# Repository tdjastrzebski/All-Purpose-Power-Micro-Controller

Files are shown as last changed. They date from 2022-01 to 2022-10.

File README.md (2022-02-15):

# All-purpose Power Micro Controller

This general purpose power micro controller features:
* Wheatstone Bridge front-end
* New Texas Instruments [INA823](https://www.ti.com/product/INA823) instrumentation amplifier (see schematic for alternatives)
* Accurate Texas Instruments [REF2030](https://www.ti.com/product/REF2030) 1.5/3V dual reference voltage source (<0.05%, 1.5 ppm/°C typ.)
* 48-pin [STM32G0B1CE](https://www.st.com/en/microcontrollers-microprocessors/stm32g0b1ce.html) 512kB flash, 144 kB RAM MPU (64kB flash minimum - see schematic for alternatives)
* Popular [Waveshare 18179](https://www.waveshare.com/1.3inch-oled-module-c.htm) 128x64 1.3" OLED display
* [STLINK-V3](https://www.st.com/en/development-tools/stlink-v3mini.html) mini and STLINK-V2 debug connectors, Segger J-Link mini supported.
* Rotary encoder and EEPROM  
* Small dimensions - only 85x50mm

Optional components:
* USB socket, can be used as a power source
* Real Time Clock (RTC) with quartz crystal oscillator
* Miniature battery or supercapacitor for RTC and memory backup
* Opto-isolated serial port (RX/TX)
* I2C port
* Two buffered DACs
* Larger [Waveshare 14747](https://www.waveshare.com/1.5inch-rgb-oled-module.htm) 128x128 1.5" RGB OLED display
* Two potentiometers for fine-tuning (gain and zero)

The device has been designed to be easily configured - e.g. here as a **Weller WSP80** station/controller powered from a standard 30V/5A bench power supply. I have built this universal controller to test some design concepts and have used it intensively for over a year as a **Weller WSP80** soldering iron controller.  
Published schematic includes probably the final 3rd version, slightly improved over what is presented on the pictures (2nd version). Controller can be easily configured to work with any NPT/PPT thermistor or a thermo-couple.

Language: C/C++

Environment: Cube IDE, Cube MX or VS Code - see [VS Code Environment Setup](Software/EnvironmentSetup.md)

License:
* [Software](Software) is released under MIT license.
* [Hardware](Hardware) KiCad design is released under Attribution-NonCommercial-NoDerivatives 4.0 International (CC BY-NC-ND 4.0) License.

Reviews:
* [ANOTHER NEAT GENERAL PURPOSE SOLDERING IRON DRIVER](https://hackaday.com/2022/01/31/another-neat-general-purpose-soldering-iron-driver) by Dave Rowntree

Improvement ideas (help wanted):
* Detecting idle state by analyzing temperature fluctuations and implementing auto sleep mode.
* Implementing self-calibration (PWM duty cycle) algorithm to increase temp precision by analyzing rate of temperature growth.
* Eliminate PWM - it adds significant ripple to the measured signal.

This repo contains complete documentation. If you are interested in building this device and need more details, please let me know rising an issue on GitHub.  
Improvements, suggestions and PRs are more than welcome - rise GitHub issue.  
Finally, if you like this project do not hesitate to give it a star to let others know it is worth checking out.

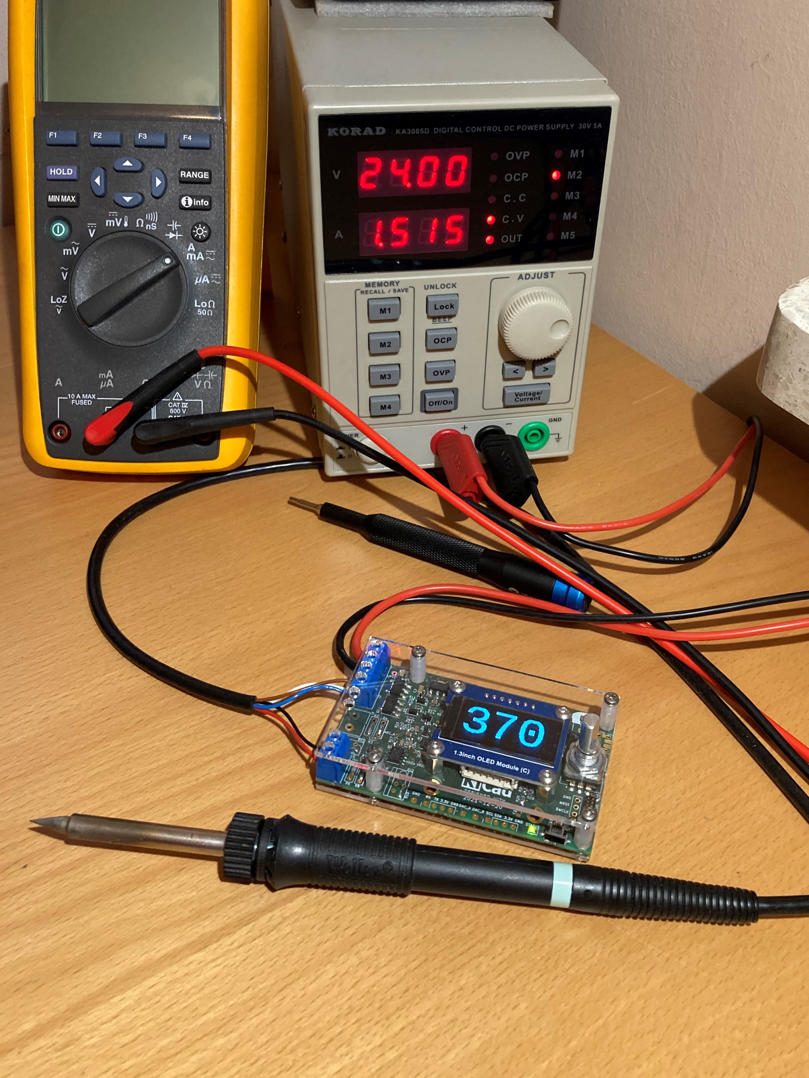
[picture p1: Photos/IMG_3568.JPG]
  
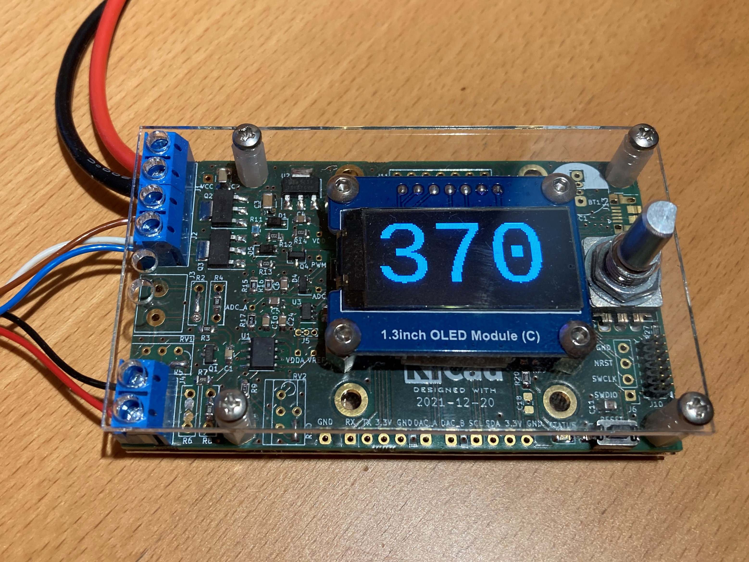
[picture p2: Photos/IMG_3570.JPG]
  
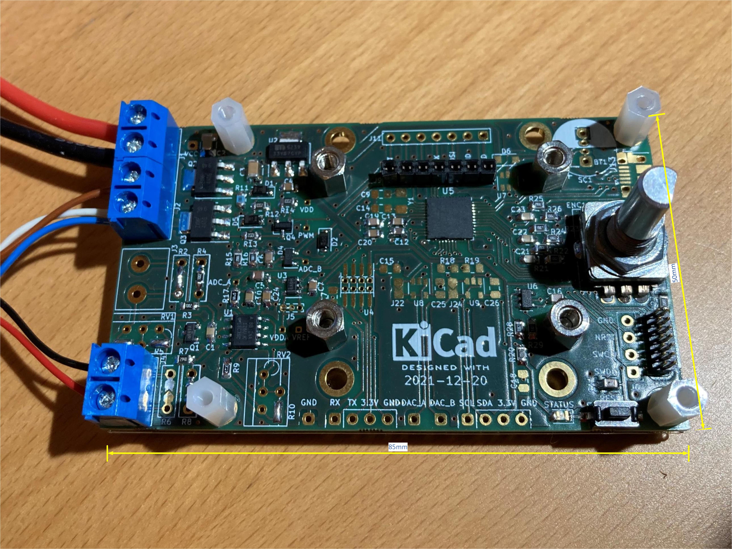
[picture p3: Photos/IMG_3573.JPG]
  
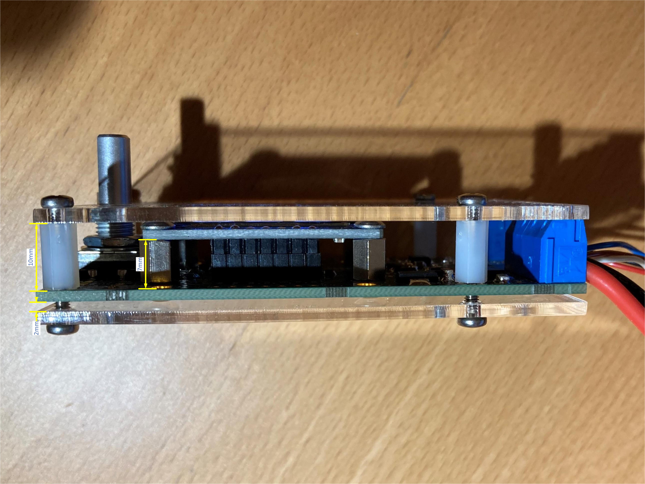
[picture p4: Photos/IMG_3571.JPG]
  
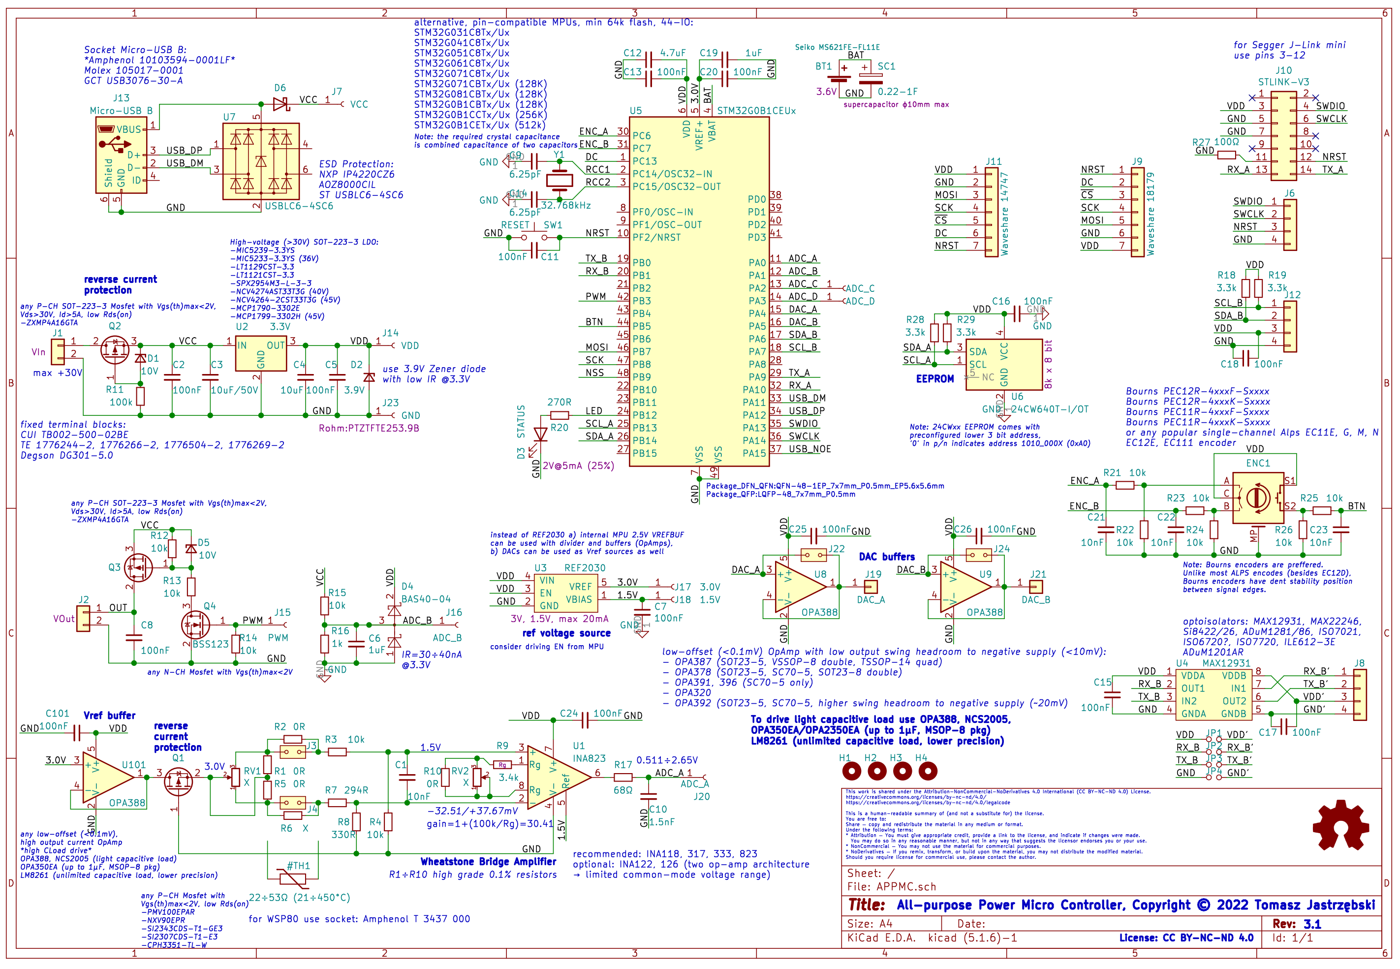
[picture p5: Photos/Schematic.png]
  
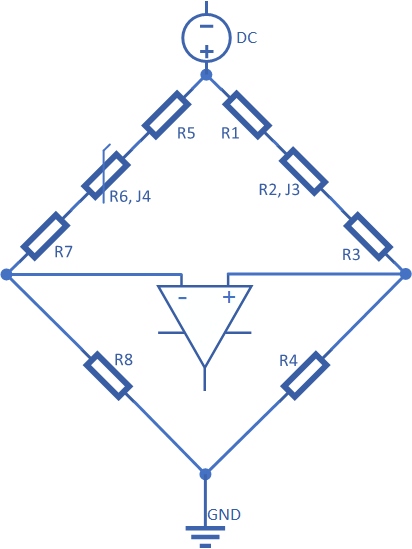
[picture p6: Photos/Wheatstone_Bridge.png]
  
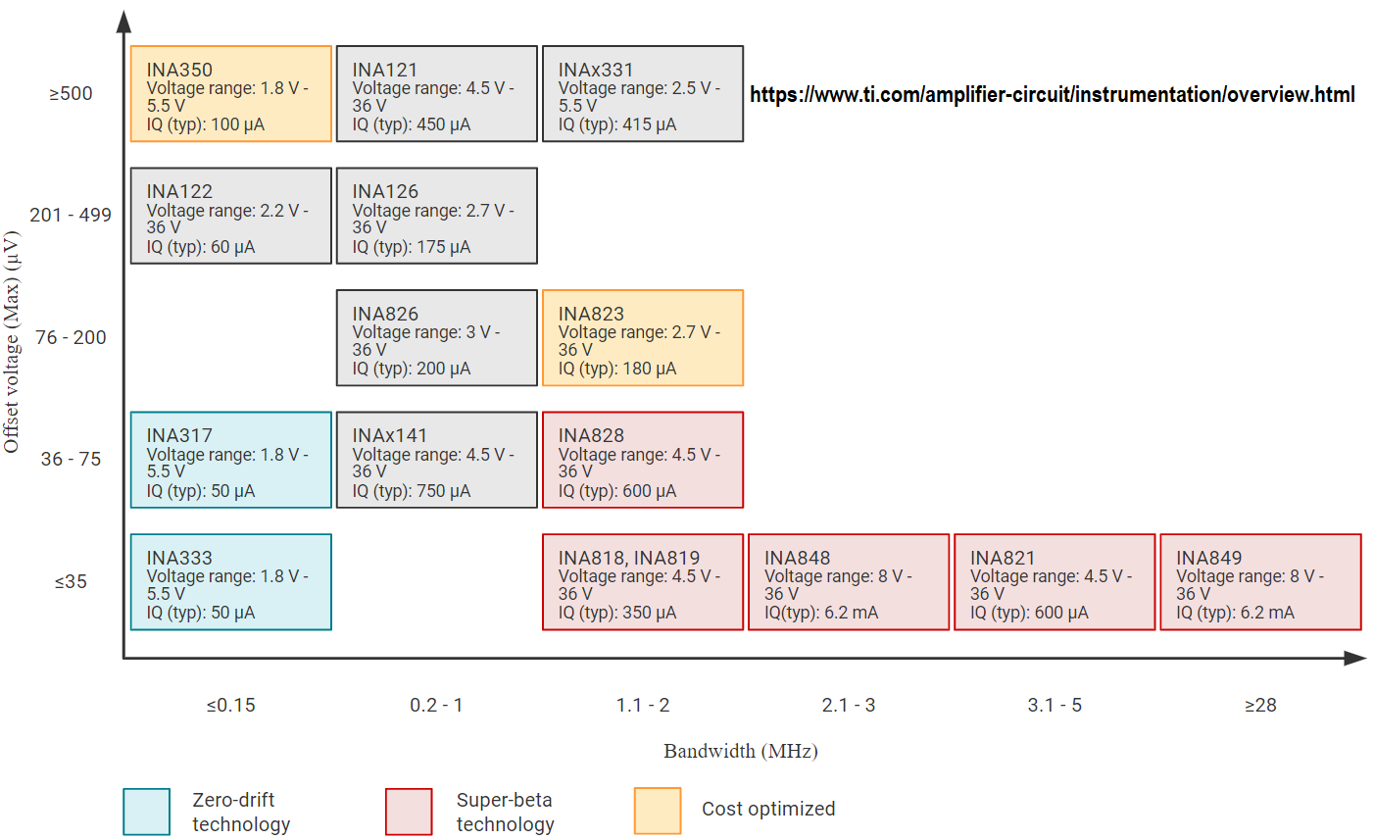
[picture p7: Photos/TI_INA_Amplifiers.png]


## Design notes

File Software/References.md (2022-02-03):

## SH1106 Libs
* https://github.com/afiskon/stm32-ssd1306
* https://github.com/desertkun/SH1106
* https://picaxeforum.co.uk/threads/fyi-comparing-the-ssd1306-and-sh1106-oled-drivers.32387
* https://www.espruino.com/SH1107
* https://www.waveshare.com/wiki/1.3inch_OLED_Module_(C)
* https://www.waveshare.com/w/upload/5/58/SH1107Datasheet.pdf

## FONTS
* https://github.com/liberationfonts/liberation-fonts (Liberation Mono)
* https://www.1001fonts.com/liberation-mono-font.html
* Consolas (TTF)
* https://github.com/fcambus/spleen
* https://oleddisplay.squix.ch (library + converter !)
* https://www.freetype.org/ + https://gitlab.freedesktop.org/freetype
* http://www.angelcode.com/products/bmfont
* https://sourceforge.net/projects/terminus-font (Terminus font)
* https://github.com/lvgl/lv_font_conv (font converter as npm package!)
* https://lvgl.io/tools/fontconverter (online font converter)

* install: `npm i lv_font_conv -g`
* `lv_font_conv --font ./fonts/liberation-mono.regular.ttf --symbols 0123456789X-?V --range 0x20 --size 64 --format * lvgl --bpp 1 --no-compress -o ./Fonts/liberation_mono.c`
* `lv_font_conv --font ./fonts/liberation-mono.regular.ttf --symbols 0123456789▲▼°☼↑↓• --size 64 --format lvgl --bpp 1 --no-compress -o ./Fonts/liberation_mono.c`
* `lv_font_conv --font ./fonts/liberation-mono.regular.ttf --symbols 0123456789 --size 64 --format dump --bpp 1 --no-compress -o ./dump`

https://www.acodersjourney.com/top-20-c-pointer-mistakes

## encoder
* https://community.st.com/s/question/0D53W00000805z2SAA/when-tim4-is-set-to-encoder-mode-what-is-the-minimum-pulse-width-it-can-capture  
* https://petoknm.wordpress.com/2015/01/05/rotary-encoder-and-stm32  
* https://stackoverflow.com/questions/39450610/stm32f4-encoder-count-is-changing-when-it-should-not (!!)  
* Note: do not use prescaler for encoder

## adac+dma
* http://e673.com/index.php/a-detailed-tutorial-on-stm32-adc-multiple-channel
* http://www.emcu.eu/how-to-use-3-channels-of-the-adc-in-dma-mode-using-cube-mx-and-atollic
* https://msalamon.pl/adc-w-stm32-na-kilka-sposobow-joystick
* https://www.youtube.com/watch?v=pLsAhJ8umJk (excellent video)
* https://www.youtube.com/c/stmicroelectronics/videos  

ADC on STM32G0: https://microgeek.eu/viewtopic.php?t=2231  
STM32G0 and STM32CubeMX 5.0: https://www.st.com/content/st_com/en/about/events/events.html/stm32g0-with-stm32cubemx-webinar.html  
* DS13560, 5.3.17 Analog-to-digital converter characteristics
* 5.3.18 Digital-to-analog converter characteristics
* 5.3.19 Voltage reference buffer characteristics
* 5.3.21 Temperature sensor characteristics
* 5.3.22 VBAT monitoring characteristics

STM32G0 Workshop: https://www.youtube.com/playlist?list=PLnMKNibPkDnG1xN9JSrrwMWt5ngQQchAa

## printf
http://www.nerdkits.com/videos/printf_and_scanf

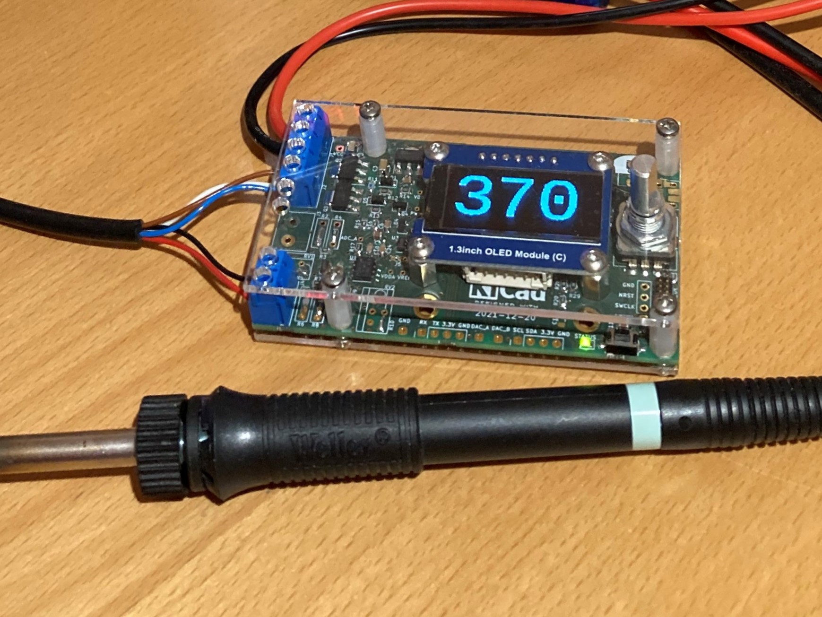
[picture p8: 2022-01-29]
Photos/IMG_3568A.jpg

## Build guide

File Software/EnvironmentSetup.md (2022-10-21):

# VS Code Environment Setup
## Prerequisites
* NodeJS + NPM
* Python + PIP
* Git
* VS Code
## pyOCD
* `pip install pyocd --upgrade`
* `pyocd pack update`
* `pyocd pack find stm32g0b1`
* `pyocd pack install STM32G0B1CEUx`
## OpenOCD
* Download the latest version from https://github.com/xpack-dev-tools/openocd-xpack/releases
or build it yourself following [this guide](https://github.com/Marus/cortex-debug/wiki/How-to-build-current-OpenOCD-version-on-Windows)
* Unzip it to `OpenOCD` folder in `C:\Program Files`
* Set `OpenOCD` system variable to 'C:\Program Files\OpenOCD'
* Add `%OpenOCD%\bin` to system PATH variable
* Set `XDG_CACHE_HOME` env variable to `%USERPROFILE%\AppData\Local\Temp` to prevent symbol cache path error
> Note: xpm utility does not really support global installations (yet), hence I suggest the above approach.
## SVD file - MPU specific
Download from https://github.com/posborne/cmsis-svd/tree/master/data/STMicro and place in the Software root folder.
## GNU Arm Embedded Toolchain
* required version: **arm-none-eabi** (bare-metal target)
* Download from https://github.com/xpack-dev-tools/arm-none-eabi-gcc-xpack
* Set `MBED_GCC_ARM_PATH` env variable to `C:\Program Files (x86)\Arm GNU Toolchain arm-none-eabi\11.2 2022.02\bin` (latest version Windows path).
* Add `MBED_GCC_ARM_PATH` env variable to Windows `Path` env variable (`%MBED_GCC_ARM_PATH%`) - if not set by the installer.
> Note: the most official build can be found [here](https://developer.arm.com/tools-and-software/open-source-software/developer-tools/gnu-toolchain/downloads) but I do not recomment using it. `arm-none-eabi-gdb` ver. 11.2 has a buggy dependency on unsupported and retired Python 2.7.
## Required NPM packages
* `npm install -g cppbuild`
* `npm install -g shx`
* `npm install -g @serialport/terminal`
## Required VS Code plug-ins
* `C/C++` (Microsoft)
* `Cortex-Debug` (marcus25) See: https://github.com/Marus/cortex-debug/wiki
## VS Code config
* Set the default VS Code terminal to `Git Bash`. Otherwise, VS Code may try to execute task NPM packages as (e.g.) PowerShell scripts.
## Recommended VS Code plug-ins
* `LinkerScript` (Zixuan Wang)
* `Arm Assembly` (dan-c-underwood)
* `Code Spell Checker` (Street Side Software)
* `Build++` (Tomasz Jastrzębski)
## ST Utilities
* [STSW-LINK009](https://www.st.com/content/st_com/en/products/development-tools/software-development-tools/stm32-software-development-tools/stm32-utilities/stsw-link009.html) ST-LINK USB Driver
* [STSW-LINK007](https://www.st.com/content/st_com/en/products/development-tools/software-development-tools/stm32-software-development-tools/stm32-programmers/stsw-link007.html) ST-LINK boards firmware upgrade

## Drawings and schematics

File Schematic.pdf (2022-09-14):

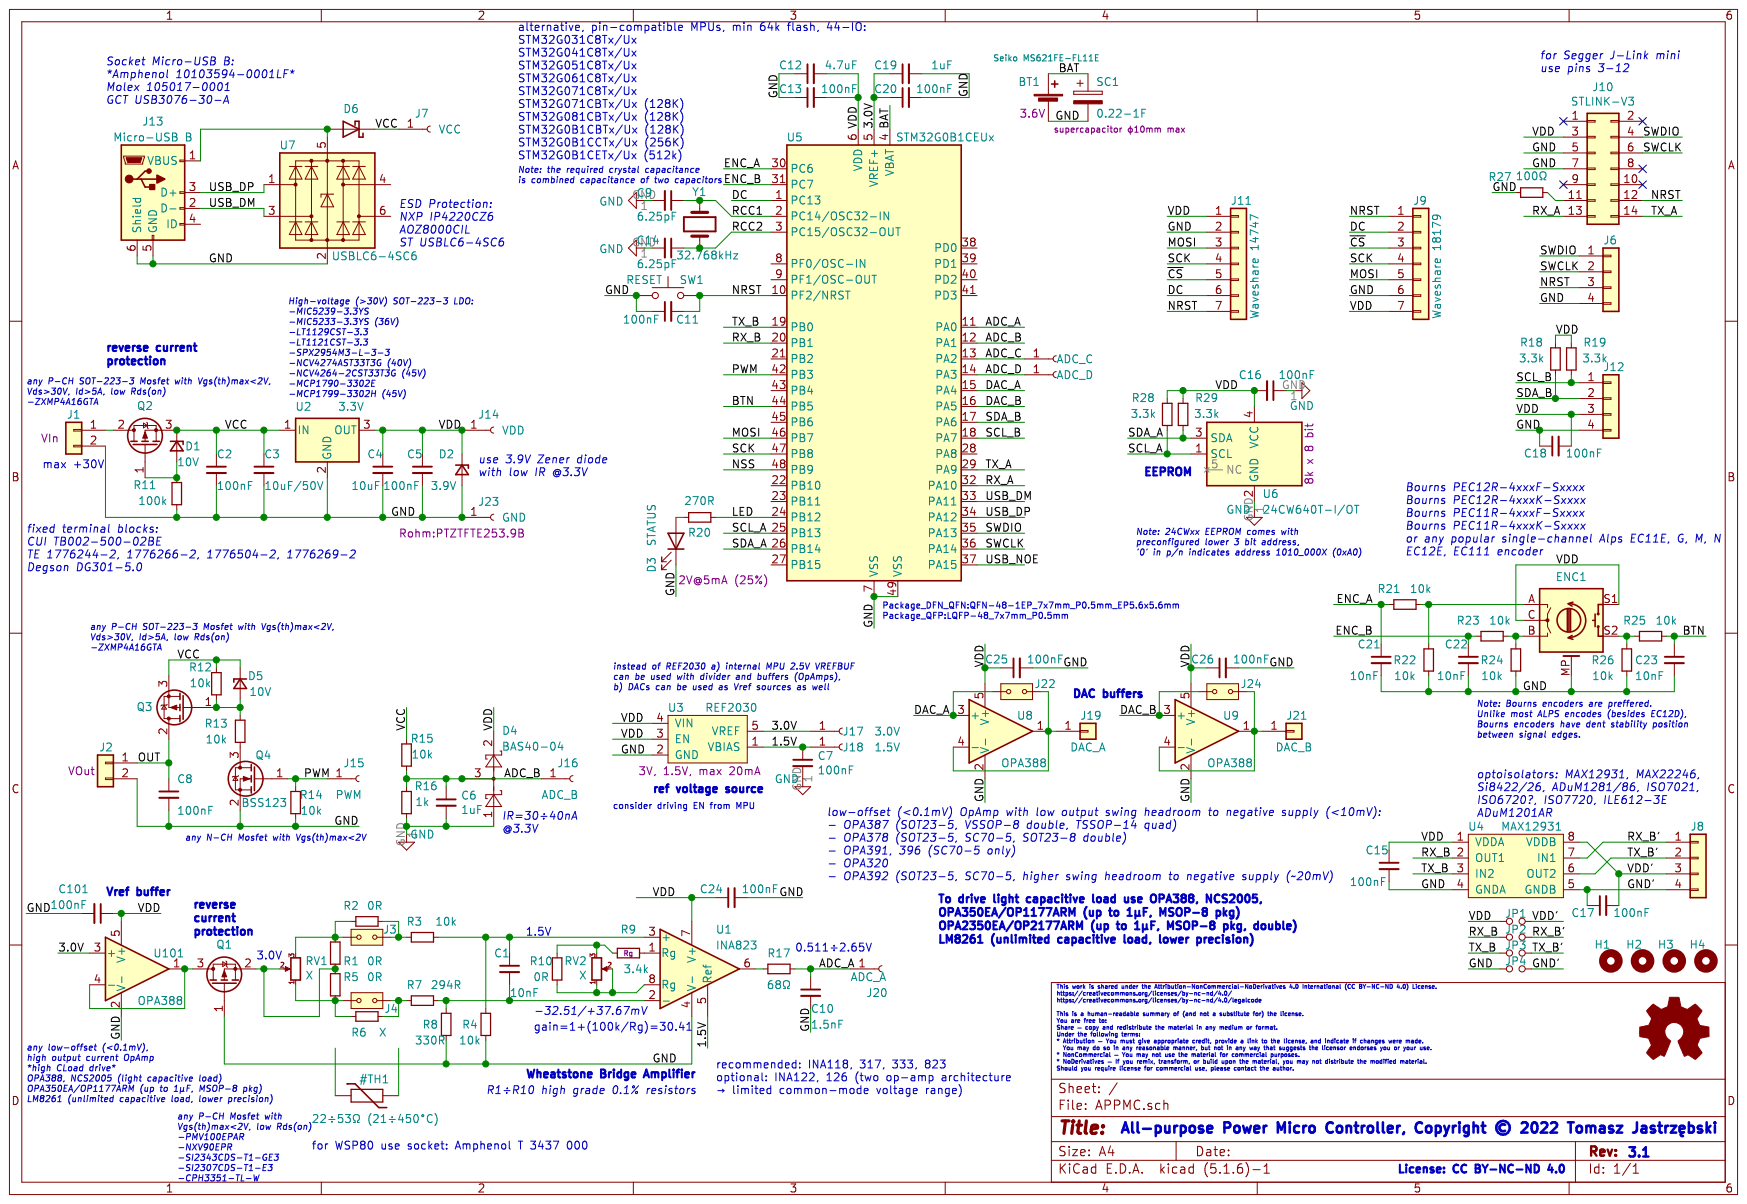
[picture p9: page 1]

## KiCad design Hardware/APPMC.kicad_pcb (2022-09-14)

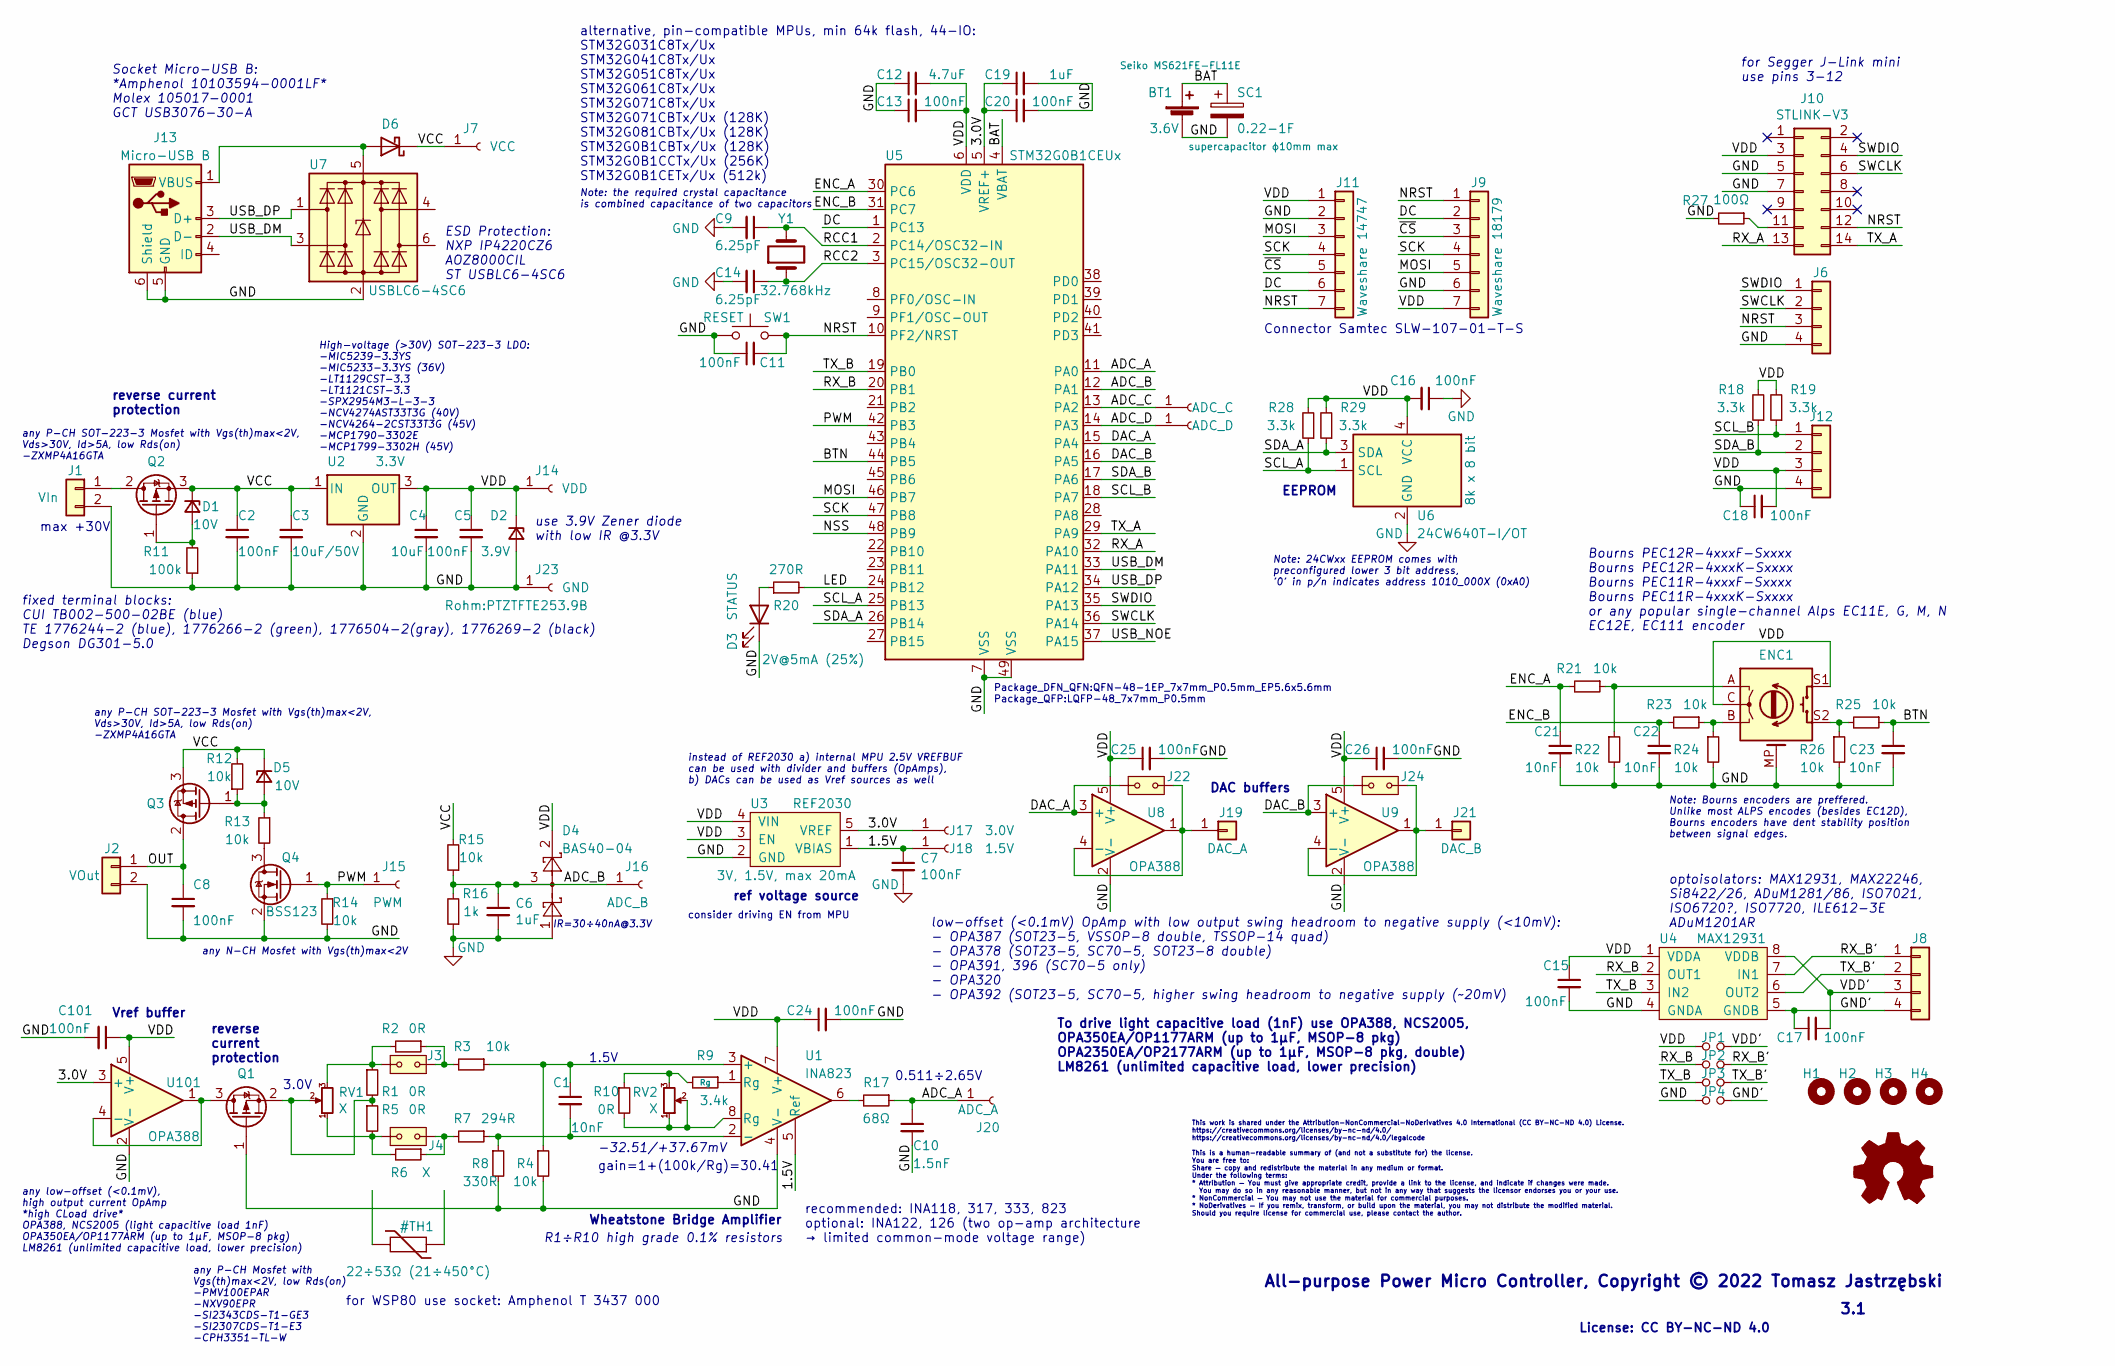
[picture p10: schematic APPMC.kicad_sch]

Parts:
BT1: Seiko MS621FE-FL11E; Seiko_MS621FE-FL11E
C1, C21, C22, C23: 10nF; C_0805_2012Metric_Pad1.15x1.40mm_HandSolder
C2, C8: 100nF; C_1210_3225Metric_Pad1.42x2.65mm_HandSolder
C3: 10uF/50V; C_1210_3225Metric_Pad1.42x2.65mm_HandSolder
C4: 10uF; C_0805_2012Metric_Pad1.15x1.40mm_HandSolder
C5, C7, C11, C13, C15, C16, C17, C18, C20, C24, C25, C26, C101: 100nF; C_0805_2012Metric_Pad1.15x1.40mm_HandSolder
C6, C19: 1uF; C_0805_2012Metric_Pad1.15x1.40mm_HandSolder
C9, C14: 6.25pF; C_0805_2012Metric_Pad1.15x1.40mm_HandSolder
C10: 1.5nF; C_0805_2012Metric_Pad1.15x1.40mm_HandSolder
C12: 4.7uF; C_0805_2012Metric_Pad1.15x1.40mm_HandSolder
D1: 10V; D_SOD-123F; Farnell 2069415
D2: 3.9V; D_SOD-123F; Farnell 2772457
D3: STATUS; D_0805_2012Metric_Pad1.15x1.40mm_HandSolder; Farnell 1318243
D4: BAS40-04; SOT-23; Farnell 2924692
D5: 10V; D_SOD-123F; Farnell 2069469
D6: D_Schottky; D_SOD-123F
ENC1: PEC16-4220F-S0024; RotaryEncoder_Alps_EC12E-Switch_Vertical_H20mm; Farnell 1520813
H1, H2, H3, H4: MountingHole; MountingHole_2.5mm_Pad_Via
J1: + 30V max; Degson_DG301-5.0-2
J2: VOut; Degson_DG301-5.0-2
J3, J4: Jumper-2B-Open; Degson_DG301-5.0-2
J6: STLINK-V2; PinHeader_1x04_P2.54mm_Vertical
J7: VCC; PinHeader_1x01_P2.54mm_Vertical
J8: Conn_01x04; PinHeader_1x04_P2.54mm_Vertical
J9: Waveshare 18179; WaveShare_18179
J10: STLINK-V3; PinHeader_2x07_P1.27mm_Vertical
J11: Waveshare 14747; WaveShare_14747_13992
J12: I2C; PinHeader_1x04_P2.54mm_Vertical
J13: Micro-USB B; USB_Micro-B_Amphenol_10103594-0001LF_Horizontal
J14: VDD; PinHeader_1x01_P1.27mm_Vertical
J15: PWM; PinHeader_1x01_P1.27mm_Vertical
J16: ADC_B; PinHeader_1x01_P1.27mm_Vertical
J17: 3.0V; PinHeader_1x01_P1.27mm_Vertical
J18: 1.5V; PinHeader_1x01_P1.27mm_Vertical
J19: DAC_A; PinHeader_1x01_P2.54mm_Vertical
J20: ADC_A; PinHeader_1x01_P1.27mm_Vertical
J21: DAC_B; PinHeader_1x01_P2.54mm_Vertical
J22, J24: Jumper-2B-Open; R_0805_2012Metric_Pad1.20x1.40mm_HandSolder_Jump
J23: GND; PinHeader_1x01_P2.54mm_Vertical
J101: ADC_C; PinHeader_1x01_P1.27mm_Vertical
J102: ADC_D; PinHeader_1x01_P1.27mm_Vertical
JP1, JP2, JP3, JP4: Jumper_NO_Small; Jumper_1x02_P1.27mm_Vertical
M4: Logo_Open_Hardware_Small; KiCad-Logo2_5mm_SilkScreen
Q1: SI2343CDS-T1-GE3; SOT-23; Farnell 2335290
Q2, Q3: ZXMP4A16GTA; SOT-223-3_TabPin2; Farnell 7564945
Q4: BSS123; TSOT-23; Farnell 9845321
R1, R5, R10: 0R; R_0805_2012Metric_Pad1.20x1.40mm_HandSolder_Jump
R2: 0R; R_0805_2012Metric_Jumper2.54
R3: 10k; R_0805_2012Metric_Pad1.20x1.40mm_HandSolder_Jump
R4: 10k; R_0805_2012Metric_Jumper2.54
R6: X; R_0805_2012Metric_Jumper2.54
R7: 294R; R_0805_2012Metric_Pad1.20x1.40mm_HandSolder_Jump
R8: 330R; R_0805_2012Metric_Jumper2.54
R9: 3.4k; R_0805_2012Metric_Pad1.20x1.40mm_HandSolder_Jump
R11: 100k; R_0805_2012Metric_Pad1.15x1.40mm_HandSolder
R12, R13, R14, R15, R21, R22, R23, R24, R25, R26: 10k; R_0805_2012Metric_Pad1.15x1.40mm_HandSolder
R16: 1k; R_0805_2012Metric_Pad1.15x1.40mm_HandSolder
R17: 68Ω; R_0805_2012Metric_Pad1.15x1.40mm_HandSolder
R18, R19, R28, R29: 3.3k; R_0805_2012Metric_Pad1.15x1.40mm_HandSolder
R20: 270R; R_0805_2012Metric_Pad1.15x1.40mm_HandSolder
R27: 100Ω; R_0805_2012Metric_Pad1.15x1.40mm_HandSolder
RV1, RV2: X; Bourns_3296WXYZ
SC1: 0.22-1F; CP_Radial_D10.0mm_P5.00mm
SW1: RESET; C&K_PTS636
U1: INA823; SOIC-8_3.9x4.9mm_P1.27mm
U2: 3.3V; SOT-223-3_TabPin2; Farnell 2857635
U3: REF2030; SOT-23-5; Farnell 3124516
U4: MAX12931; SOIC-8_3.9x4.9mm_P1.27mm
U5: STM32G0B1CEUx; QFN-48-1EP_7x7mm_P0.5mm_EP5.6x5.6mm
U6: 24CW640T-I/OT; SOT-23-5
U7: USBLC6-4SC6; SOT-23-6
U8, U9, U101: OPA388; SOT-23-5
Y1: 32.768kHz; Abracon_ABS07-HS

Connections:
/1.5V: C7.1, J18.1, U1.5 (Ref), U3.1 (VBIAS)
/3.0V: C19.1, C20.1, J17.1, U3.5 (VREF), U5.5 (VREF+), U101.3 (+)
/ADC_A: C10.1, J20.1, R17.1, U5.11 (PA0)
/ADC_B: C6.1, D4.3, J16.1, R15.1, R16.2, U5.12 (PA1)
/ADC_C: J101.1, U5.13 (PA2)
/ADC_D: J102.1, U5.14 (PA3)
/BAT: BT1.1 (+), SC1.1, U5.4 (VBAT)
/BTN: C23.1, R25.1, U5.44 (PB5)
/DAC_A: J22.1, U5.15 (PA4), U8.3 (+)
/DAC_B: J24.1, U5.16 (PA5), U9.3 (+)
/DC: J9.2, J11.6, U5.1 (PC13)
/ENC_A: C21.1, R21.2, U5.30 (PC6)
/ENC_B: C22.1, R23.2, U5.31 (PC7)
/GND': C17.1, J8.4, JP4.2, U4.5 (GNDB)
/LED: R20.2, U5.24 (PB12)
/MOSI: J9.5, J11.3, U5.46 (PB7)
/NRST: C11.2, J6.3, J9.1, J10.12, J11.7, SW1.1, U5.10 (PF2/NRST)
/OUT: C8.1, J2.1, Q3.2 (D)
/PWM: J15.1, Q4.1 (G), R14.1, U5.42 (PB3)
/RCC1: C9.1, U5.2 (PC14/OSC32-IN), Y1.2
/RCC2: C14.1, U5.3 (PC15/OSC32-OUT), Y1.1
/RX_A: J10.13, U5.32 (PA10)
/RX_B: JP2.1, U4.2 (OUT1), U5.20 (PB1)
/RX_B': J8.1, JP2.2, U4.7 (IN1)
/SCK: J9.4, J11.4, U5.47 (PB8)
/SCL_A: R28.1, U5.25 (PB13), U6.1 (SCL)
/SCL_B: J12.1, R19.1, U5.18 (PA7)
/SDA_A: R29.1, U5.26 (PB14), U6.3 (SDA)
/SDA_B: J12.2, R18.1, U5.17 (PA6)
/SWCLK: J6.2, J10.6, U5.36 (PA14)
/SWDIO: J6.1, J10.4, U5.35 (PA13)
/TX_A: J10.14, U5.29 (PA9)
/TX_B: JP3.1, U4.3 (IN2), U5.19 (PB0)
/TX_B': J8.2, JP3.2, U4.6 (OUT2)
/USB_DM: J13.2 (D-), U5.33 (PA11), U7.3 (I/O2)
/USB_DP: J13.3 (D+), U5.34 (PA12), U7.1 (I/O1)
/VCC: C2.1, C3.1, D1.1 (K), D5.1 (K), D6.1 (K), J7.1, Q2.3 (S), Q3.3 (S), R12.2, R15.2, U2.1 (IN)
/VDD: C4.1, C5.1, C12.2, C13.2, C15.1, C16.2, C18.2, C24.1, C25.1, C26.1, C101.1, D2.1 (K), D4.2, ENC1.C, ENC1.S1, J9.7, J10.3, J11.1, J12.3, J14.1, JP1.1, R18.2, R19.2, R28.2, R29.2, U1.7 (V+), U2.3 (OUT), U3.3 (EN), U3.4 (VIN), U4.1 (VDDA), U5.6 (VDD), U6.4 (VCC), U8.5 (V+), U9.5 (V+), U101.5 (V+)
/VDD': C17.2, J8.3, JP1.2, U4.8 (VDDB)
/~CS: J9.3, J11.5
GND: BT1.2 (-), C2.2, C3.2, C4.2, C5.2, C6.2, C7.2, C8.2, C9.2, C10.2, C11.1, C12.1, C13.1, C14.2, C15.2, C16.1, C18.1, C19.2, C20.2, C21.2, C22.2, C23.2, C24.2, C25.2, C26.2, C101.2, D2.2 (A), D3.1 (K), D4.1, ENC1.MP, J1.2, J2.2, J6.4, J9.6, J10.5, J10.7, J11.2, J12.4, J13.5 (GND), J13.6 (Shield), J23.1, JP4.1, Q1.1 (G), Q4.2 (S), R4.2, R8.2, R11.1, R14.2, R16.1, R22.2, R24.2, R26.2, R27.2, SC1.2, SW1.2, U1.4 (V-), U2.2 (GND), U3.2 (GND), U4.4 (GNDA), U5.7 (VSS), U5.49 (VSS), U6.2 (GND), U7.2 (GND), U8.2 (V-), U9.2 (V-), U101.2 (V-)
unnamed: C1.1, R3.1, R4.1, U1.3 (+)
unnamed: C1.2, R7.1, R8.1, U1.2 (-)
unnamed: D1.2 (A), Q2.1 (G), R11.2
unnamed: D3.2 (A), R20.1
unnamed: D5.2 (A), Q3.1 (G), R12.1, R13.1
unnamed: D6.2 (A), J13.1 (VBUS), U7.5 (VBUS)
unnamed: ENC1.A, R21.1, R22.1
unnamed: ENC1.B, R23.1, R24.1
unnamed: ENC1.S2, R25.2, R26.1
unnamed: J1.1, Q2.2 (D)
unnamed: J3.1, R2.1, R3.2
unnamed: J3.2, R1.1, R2.2, RV1.3
unnamed: J4.1, R5.2, R6.2, RV1.1
unnamed: J4.2, R6.1, R7.2
unnamed: J10.11, R27.1
unnamed: J19.1, J22.2, U8.1, U8.4 (-)
unnamed: J21.1, J24.2, U9.1, U9.4 (-)
unnamed: Q1.2 (S), R1.2, R5.1, RV1.2
unnamed: Q1.3 (D), U101.1, U101.4 (-)
unnamed: Q4.3 (D), R13.2
unnamed: R9.1, U1.1 (Rg)
unnamed: R9.2, R10.1, RV2.3
unnamed: R10.2, RV2.1, RV2.2, U1.8 (Rg)
unnamed: R17.2, U1.6

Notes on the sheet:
DAC buffers
ESD Protection: NXP IP4220CZ6 AOZ8000CIL ST USBLC6-4SC6
use 3.9V Zener diode with low IR @3.3V
Connector Samtec SLW-107-01-T-S
All-purpose Power Micro Controller, Copyright © 2022 Tomasz Jastrzębski
ref voltage source
for Segger J-Link mini use pins 3-12
fixed terminal blocks: CUI TB002-500-02BE (blue) TE 1776244-2 (blue), 1776266-2 (green), 1776504-2(gray), 1776269-2 (black) Degson DG301-5.0
reverse current protection
1.5V
Wheatstone Bridge Amplifier
any P-CH SOT-223-3 Mosfet with Vgs(th)max<2V, Vds>30V, Id>5A, low Rds(on) -ZXMP4A16GTA
recommended: INA118, 317, 333, 823 optional: INA122, 126 (two op-amp architecture → limited common-mode voltage range)
low-offset (<0.1mV) OpAmp with low output swing headroom to negative supply (<10mV): - OPA387 (SOT23-5, VSSOP-8 double, TSSOP-14 quad) - OPA378 (SOT23-5, SC70-5, SOT23-8 double) - OPA391, 396 (SC70-5 only) - OPA320 - OPA392 (SOT23-5, SC70-5, higher swing headroom to negative supply (~20mV)
3.0V
Bourns PEC12R-4xxxF-Sxxxx Bourns PEC12R-4xxxK-Sxxxx Bourns PEC11R-4xxxF-Sxxxx Bourns PEC11R-4xxxK-Sxxxx or any popular single-channel Alps EC11E, G, M, N EC12E, EC111 encoder
any low-offset (<0.1mV), high output current OpAmp *high CLoad drive* OPA388, NCS2005 (light capacitive load 1nF) OPA350EA/OP1177ARM (up to 1µF, MSOP-8 pkg) LM8261 (unlimited capacitive load, lower precision)
3.1
License: CC BY-NC-ND 4.0
EEPROM
instead of REF2030 a) internal MPU 2.5V VREFBUF can be used with divider and buffers (OpAmps), b) DACs can be used as Vref sources as well
This work is shared under the Attribution-NonCommercial-NoDerivatives 4.0 International (CC BY-NC-ND 4.0) License. https://creativecommons.org/licenses/by-nc-nd/4.0/ https://creativecommons.org/licenses/by-nc-nd/4.0/legalcode This is a human-readable summary of (and not a substitute for) the licens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
max +30V
-32.51/+37.67mV
R1÷R10 high grade 0.1% resistors
alternative, pin-compatible MPUs, min 64k flash, 44-IO: STM32G031C8Tx/Ux STM32G041C8Tx/Ux STM32G051C8Tx/Ux STM32G061C8Tx/Ux STM32G071C8Tx/Ux STM32G071CBTx/Ux (128K) STM32G081CBTx/Ux (128K) STM32G0B1CBTx/Ux (128K) STM32G0B1CCTx/Ux (256K) STM32G0B1CETx/Ux (512k)
Socket Micro-USB B: *Amphenol 10103594-0001LF* Molex 105017-0001 GCT USB3076-30-A
Note: 24CWxx EEPROM comes with preconfigured lower 3 bit address, '0' in p/n indicates address 1010_000X (0xA0)
optoisolators: MAX12931, MAX22246, Si8422/26, ADuM1281/86, ISO7021, ISO6720?, ISO7720, ILE612-3E ADuM1201AR
IR=30÷40nA@3.3V
reverse current protection
High-voltage (>30V) SOT-223-3 LDO: -MIC5239-3.3YS -MIC5233-3.3YS (36V) -LT1129CST-3.3 -LT1121CST-3.3 -SPX2954M3-L-3-3 -NCV4274AST33T3G (40V) -NCV4264-2CST33T3G (45V) -MCP1790-3302E -MCP1799-3302H (45V)
0.511÷2.65V
Note: Bourns encoders are preffered. Unlike most ALPS encodes (besides EC12D), Bourns encoders have dent stability position between signal edges.
consider driving EN from MPU
Vref buffer
any P-CH Mosfet with Vgs(th)max<2V, low Rds(on) -PMV100EPAR -NXV90EPR -SI2343CDS-T1-GE3 -SI2307CDS-T1-E3 -CPH3351-TL-W
To drive light capacitive load (1nF) use OPA388, NCS2005, OPA350EA/OP1177ARM (up to 1µF, MSOP-8 pkg) OPA2350EA/OP2177ARM (up to 1µF, MSOP-8 pkg, double) LM8261 (unlimited capacitive load, lower precision)
Note: the required crystal capacitance is combined capacitance of two capacitors
any N-CH Mosfet with Vgs(th)max<2V

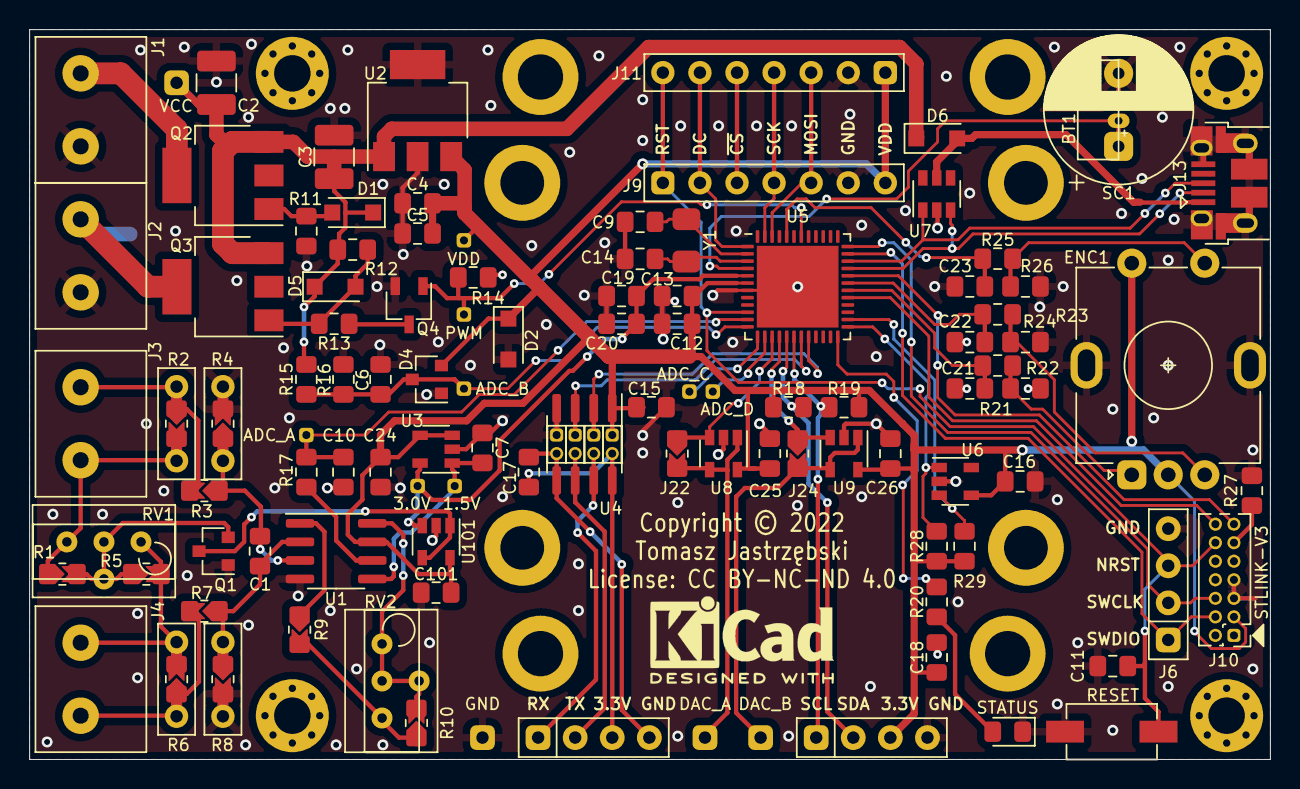
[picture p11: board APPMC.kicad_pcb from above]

Board: 2 copper layers, 85.0 x 50.0 mm, 117 parts (1 on the bottom side), 65 nets.

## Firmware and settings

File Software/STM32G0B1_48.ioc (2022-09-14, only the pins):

Mcu.UserName=STM32G0B1CEUx
PA0.GPIO_Label=ADC_A
PA0.Signal=ADC1_IN0
PA1.GPIO_Label=ADC_B
PA1.Signal=ADC1_IN1
PA10.GPIO_Label=RX_A
PA10.Signal=USART1_RX
PA13.GPIO_Label=SWDIO
PA13.Signal=SYS_SWDIO
PA14-BOOT0.GPIO_Label=SWCLK
PA14-BOOT0.Signal=SYS_SWCLK
PA4.GPIO_Label=DAC_A
PA4.Signal=COMP_DAC11_group
PA5.GPIO_Label=DAC_B
PA5.Signal=COMP_DAC12_group
PA6.GPIO_Label=SDA_B
PA6.Signal=I2C3_SDA
PA7.GPIO_Label=SCL_B
PA7.Signal=I2C3_SCL
PA9.GPIO_Label=TX_A
PA9.Signal=USART1_TX
PB0.GPIO_Label=TX_B
PB0.Signal=USART5_TX
PB1.GPIO_Label=RX_B
PB1.Signal=USART5_RX
PB12.GPIO_Label=LED
PB12.Signal=GPIO_Output
PB13.GPIO_Label=SCL_A
PB13.Signal=I2C2_SCL
PB14.GPIO_Label=SDA_A
PB14.Signal=I2C2_SDA
PB3.GPIO_Label=PWM
PB3.Signal=S_TIM1_CH2
PB5.GPIO_Label=BTN
PB5.Signal=GPXTI5
PB7.GPIO_Label=MOSI
PB7.Signal=SPI2_MOSI
PB8.GPIO_Label=SCK
PB8.Signal=SPI2_SCK
PB9.GPIO_Label=CS
PB9.Signal=SPI2_NSS
PC13.GPIO_Label=DC
PC13.Signal=GPIO_Output
PC6.GPIO_Label=ENC2
PC6.Signal=S_TIM3_CH1
PC7.GPIO_Label=ENC1
PC7.Signal=S_TIM3_CH2

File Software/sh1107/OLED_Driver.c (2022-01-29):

/******************************************************************************
***************************Intermediate driver layer***************************
* | file      :	OLED_Driver.c
* |	version		:	V1.0
* | date			:	2020-06-17
* | function	:	SH1107 Drive function
	
note:
Image scanning:
Please use progressive scanning to generate images or fonts			
******************************************************************************/

#include "OLED_Driver.h"
#include "stdio.h"

/*******************************************************************************
function:
			Hardware reset
*******************************************************************************/
static void OLED_Reset(void)
{
    OLED_RST_1;
    Driver_Delay_ms(100);
    OLED_RST_0;
    Driver_Delay_ms(100);
    OLED_RST_1;
    Driver_Delay_ms(100);
}

/*******************************************************************************
function:
		Write register address and commond
*******************************************************************************/
void OLED_WriteReg(uint8_t Reg)
{
#if USE_SPI_4W
    OLED_DC_0;
    OLED_CS_0;
    SPI4W_Write_Byte(Reg);
    OLED_CS_1;
#elif USE_IIC
    I2C_Write_Byte(Reg,IIC_CMD);
#endif
}

/*******************************************************************************
function:
		Write register address and data
*******************************************************************************/
void OLED_WriteData(uint8_t Data)
{
#if USE_SPI_4W
    OLED_DC_1;
    OLED_CS_0;
    SPI4W_Write_Byte(Data);
    OLED_CS_1;
#elif USE_IIC
    I2C_Write_Byte(Data,IIC_RAM);
#endif
}

/*******************************************************************************
function:
		Common register initialization
*******************************************************************************/
static void OLED_InitReg(void)
{
    OLED_WriteReg(0xae);	/*turn off OLED display*/

    OLED_WriteReg(0x00);	/*set lower column address*/ 
    OLED_WriteReg(0x10);	/*set higher column address*/ 

    OLED_WriteReg(0xB0);	/*set page address*/ 
	
    OLED_WriteReg(0xdc);	/*set display start line*/ 
    OLED_WriteReg(0x00);  

    OLED_WriteReg(0x81);	/*contract control*/ 
    OLED_WriteReg(0x6f);	/*128*/ 
    OLED_WriteReg(0x21);  /* Set Memory addressing mode (0x20/0x21) */ 
	
    OLED_WriteReg(0xa0);  /*set segment remap*/ 
    OLED_WriteReg(0xc0);  /*Com scan direction*/ 
    OLED_WriteReg(0xa4);	/*Disable Entire Display On (0xA4/0xA5)*/ 

    OLED_WriteReg(0xa6);	/*normal / reverse*/
    OLED_WriteReg(0xa8);	/*multiplex ratio*/ 
    OLED_WriteReg(0x3f);  /*duty = 1/64*/ 
  
    OLED_WriteReg(0xd3);  /*set display offset*/ 
    OLED_WriteReg(0x60);

    OLED_WriteReg(0xd5);	/*set osc division*/ 
    OLED_WriteReg(0x41);
		
    OLED_WriteReg(0xd9);  /*set pre-charge period*/ 
    OLED_WriteReg(0x22);   

    OLED_WriteReg(0xdb);  /*set vcomh*/ 
    OLED_WriteReg(0x35);  

    OLED_WriteReg(0xad);  /*set charge pump enable*/ 
    OLED_WriteReg(0x8a);	/*Set DC-DC enable (a=0:disable; a=1:enable) */
}


/********************************************************************************
function:
			initialization
********************************************************************************/
void OLED_Init()
{
    //Hardware reset
    OLED_Reset();

    //Set the initialization register
    OLED_InitReg();
    Driver_Delay_ms(200);

    //Turn on the OLED display
    OLED_WriteReg(0xaf);
}


/********************************************************************************
function:
			Clear screen
********************************************************************************/
void OLED_Clear()
{
	UWORD Width, Height, column;
	Width = (OLED_WIDTH % 8 == 0)? (OLED_WIDTH / 8 ): (OLED_WIDTH / 8 + 1);
	Height = OLED_HEIGHT;  
	OLED_WriteReg(0xb0); 	//Set the row  start address
	for (UWORD j = 0; j < Height; j++) {
		column = 63 - j;
		OLED_WriteReg(0x00 + (column & 0x0f));  //Set column low start address
		OLED_WriteReg(0x10 + (column >> 4));  //Set column higt start address
		for (UWORD i = 0; i < Width; i++) {
			OLED_WriteData(0x00);
		 }
	}
}

/********************************************************************************
function:	Update all memory to OLED
********************************************************************************/
void OLED_Display(UBYTE *Image)
{		
	UWORD Width, Height, column, temp;
	Width = (OLED_WIDTH % 8 == 0)? (OLED_WIDTH / 8 ): (OLED_WIDTH / 8 + 1);
	Height = OLED_HEIGHT;   
	OLED_WriteReg(0xb0); 	//Set the row  start address
	for (UWORD j = 0; j < Height; j++) {
		column = 63 - j;
		OLED_WriteReg(0x00 + (column & 0x0f));  //Set column low start address
		OLED_WriteReg(0x10 + (column >> 4));  //Set column higt start address
		for (UWORD i = 0; i < Width; i++) {
			temp = Image[i + j * Width];
			temp = reverse(temp);	//reverse the buffer
			OLED_WriteData(temp);
		 }
	}   
}

/********************************************************************************
function:	reverse a byte data
********************************************************************************/
UBYTE reverse(UBYTE temp)
{
	temp = ((temp & 0x55) << 1) | ((temp & 0xaa) >> 1);
	temp = ((temp & 0x33) << 2) | ((temp & 0xcc) >> 2);
	temp = ((temp & 0x0f) << 4) | ((temp & 0xf0) >> 4);  
	return temp;
}

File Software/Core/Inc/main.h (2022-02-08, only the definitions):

#define TIMERS_CLOCK_FREQ 16000000
#define DC_Pin GPIO_PIN_13
#define DC_GPIO_Port GPIOC
#define ADC_A_Pin GPIO_PIN_0
#define ADC_A_GPIO_Port GPIOA
#define ADC_B_Pin GPIO_PIN_1
#define ADC_B_GPIO_Port GPIOA
#define DAC_A_Pin GPIO_PIN_4
#define DAC_A_GPIO_Port GPIOA
#define DAC_B_Pin GPIO_PIN_5
#define DAC_B_GPIO_Port GPIOA
#define SDA_B_Pin GPIO_PIN_6
#define SDA_B_GPIO_Port GPIOA
#define SCL_B_Pin GPIO_PIN_7
#define SCL_B_GPIO_Port GPIOA
#define TX_B_Pin GPIO_PIN_0
#define TX_B_GPIO_Port GPIOB
#define RX_B_Pin GPIO_PIN_1
#define RX_B_GPIO_Port GPIOB
#define LED_Pin GPIO_PIN_12
#define LED_GPIO_Port GPIOB
#define SCL_A_Pin GPIO_PIN_13
#define SCL_A_GPIO_Port GPIOB
#define SDA_A_Pin GPIO_PIN_14
#define SDA_A_GPIO_Port GPIOB
#define TX_A_Pin GPIO_PIN_9
#define TX_A_GPIO_Port GPIOA
#define ENC2_Pin GPIO_PIN_6
#define ENC2_GPIO_Port GPIOC
#define ENC1_Pin GPIO_PIN_7
#define ENC1_GPIO_Port GPIOC
#define RX_A_Pin GPIO_PIN_10
#define RX_A_GPIO_Port GPIOA
#define SWDIO_Pin GPIO_PIN_13
#define SWDIO_GPIO_Port GPIOA
#define SWCLK_Pin GPIO_PIN_14
#define SWCLK_GPIO_Port GPIOA
#define PWM_Pin GPIO_PIN_3
#define PWM_GPIO_Port GPIOB
#define BTN_Pin GPIO_PIN_5
#define BTN_GPIO_Port GPIOB
#define BTN_EXTI_IRQn EXTI4_15_IRQn
#define MOSI_Pin GPIO_PIN_7
#define MOSI_GPIO_Port GPIOB
#define SCK_Pin GPIO_PIN_8
#define SCK_GPIO_Port GPIOB
#define CS_Pin GPIO_PIN_9
#define CS_GPIO_Port GPIOB

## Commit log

2022-01-29 initial version
    [APPMC-WSP80.sch, APPMC.kicad_pcb, APPMC.sch]
2022-01-30 docs/license info update
    [APPMC.kicad_pcb, APPMC.sch]
2022-02-05 MPU list errata
    [APPMC-WSP80.sch, APPMC.sch]
2022-02-05 values adjusted
    [APPMC-WSP80.sch, APPMC.sch]
2022-02-06 docs update
    [APPMC-WSP80.sch, APPMC.sch]
2022-02-06 docs & VS Code settings update
    [APPMC-WSP80.sch, APPMC.sch]
2022-02-08 updates to 3.1
    [APPMC-WSP80.sch, APPMC.kicad_pcb, APPMC.sch]
2022-02-08 update to 3.1
    [APPMC-WSP80.sch, APPMC.sch]
2023-07-07 build file and VS Code settings fix
    [master.cpp]

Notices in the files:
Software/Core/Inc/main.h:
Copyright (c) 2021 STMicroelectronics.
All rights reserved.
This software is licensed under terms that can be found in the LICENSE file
